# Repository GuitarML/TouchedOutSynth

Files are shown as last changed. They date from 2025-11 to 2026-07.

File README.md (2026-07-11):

# TouchedOut Sampler

The TouchedOut Polysynth is a polyphonic capacitive touch synth on a PCB, using the Daisy Seed. 
Two Adafruit MPR121 capacitive touch modules are used for keys and buttons. The firmware 
was designed and built using Arduino IDE with DaisyDuino. See Electrosmith's tutorials for
setting up the DaisyDuino environment with Arduino IDE. This repo also includes the
KiCad schematic and pcb files for ordering your own from a PCB manufacturer (JLCPcb gerbers provided).

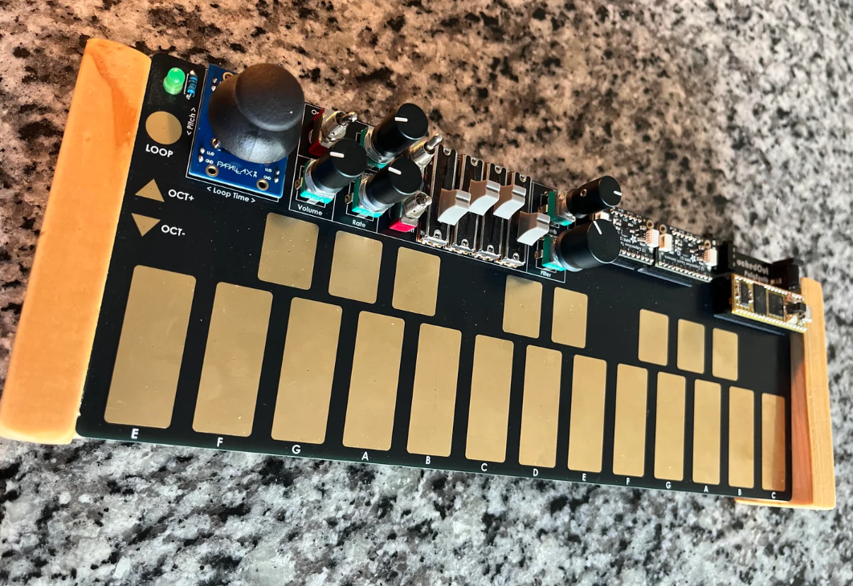
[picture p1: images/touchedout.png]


[Video Demos on YouTube](https://youtu.be/tRJoIYXkm-U?si=PkRd3XZ30BAMkGUb)

## Microphone Circuit
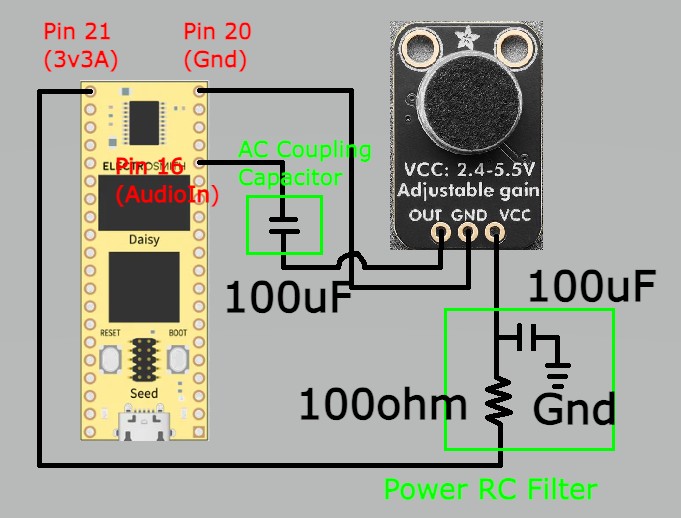
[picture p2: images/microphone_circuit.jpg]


The added microphone circuit for the TouchedOutSampler firmware is shown above. The mic used is from [Adafruit](https://www.adafruit.com/product/1063?srsltid=AfmBOooQ07_40sVdienoSQDztJte4-cMyLQY7wpDJVhW7ct12bVJHef1), MAX4466.
The 100uF capacitor on the audio line couples the audio to AC, as the output from the MAX4466 is DC coupled.
The RC filter using the 100 ohm resistior and 100uF capacitor was required for noise reduction. There 
is alot of noise coming from the Daisy Seed 3v3A power, but this RC filter does a good job of filtering it out. 

## Arduino IDE Setup

Follow this tutorial to set up DaisyDuino in Arduino IDE:
[How to Add Daisy Support to Arduino IDE](https://youtu.be/UyQWK8JFTps?si=kI6pP10nuPIkyu_V)

IMPORTANT!!! Updating Adafruit_MPR121 package to version 1.2.0 breaks functionality due to I2C incompatibilites. Use Adafruit_MPR121 version 1.1.3

Use these Tools settings in your Arduino IDE (pay attention to -O3 optimization and USB support: generic serial supercede USART)

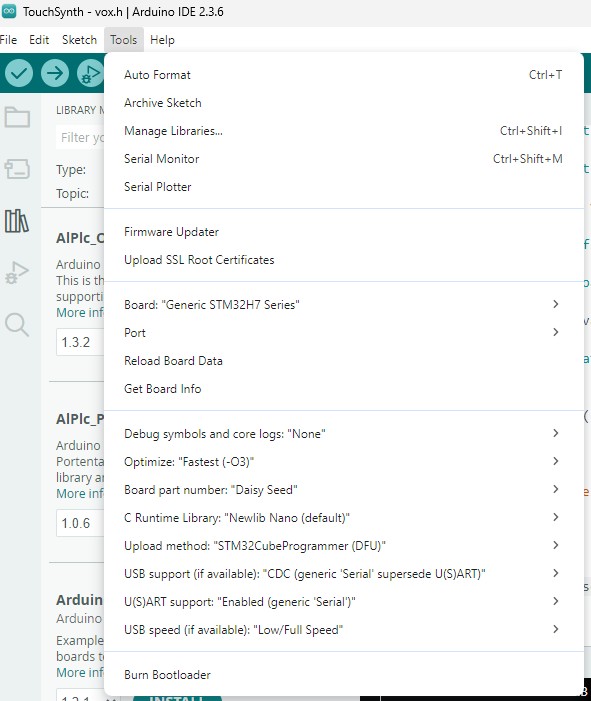
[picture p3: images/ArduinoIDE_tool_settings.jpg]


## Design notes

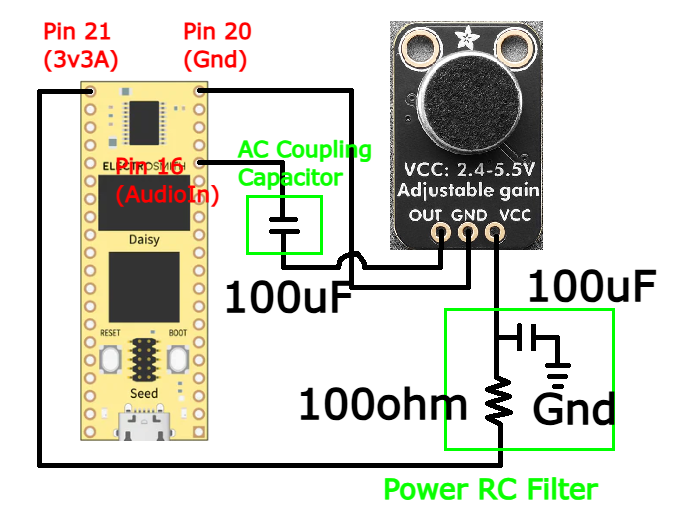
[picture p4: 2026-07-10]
images/microphone_circuit.png

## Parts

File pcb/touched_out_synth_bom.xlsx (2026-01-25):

Part | Qty | Description | Purchase Link
Daisy Seed | 1 |  | https://electro-smith.com/products/daisy-seed
MPR121 Module | 2 |  | https://www.adafruit.com/product/1982
2 Axis Joystick | 1 |  | https://www.adafruit.com/product/245
10K Linear Potentiometer | 5 |  | https://lovemyswitches.com/9mm-potentiometers-1-4-smooth-shaft-vertical-pcb-mount/ | Alternate small knob from Adafruit: https://www.adafruit.com/product/4133
On Off On Toggle | 1 |  | https://lovemyswitches.com/taiway-spdt-on-off-on-switch-pcb-long-shaft/
On On Toggle | 2 |  | https://lovemyswitches.com/taiway-sub-mini-spdt-on-on-switch-solder-lug-short-shaft/
10K 35mm Slide Potentiometer | 4 |  | https://www.adafruit.com/product/4271
1/8" Jack | 2 |  | https://www.taydaelectronics.com/pj-320a-3-5-mm-audio-socket-through-hole-pcb-silver-plated.html
1k Resistor | 1
LED | 1
10 ohm Resistor | 1
33 ohm Resistor | 1
TouchedOut PCB | 1

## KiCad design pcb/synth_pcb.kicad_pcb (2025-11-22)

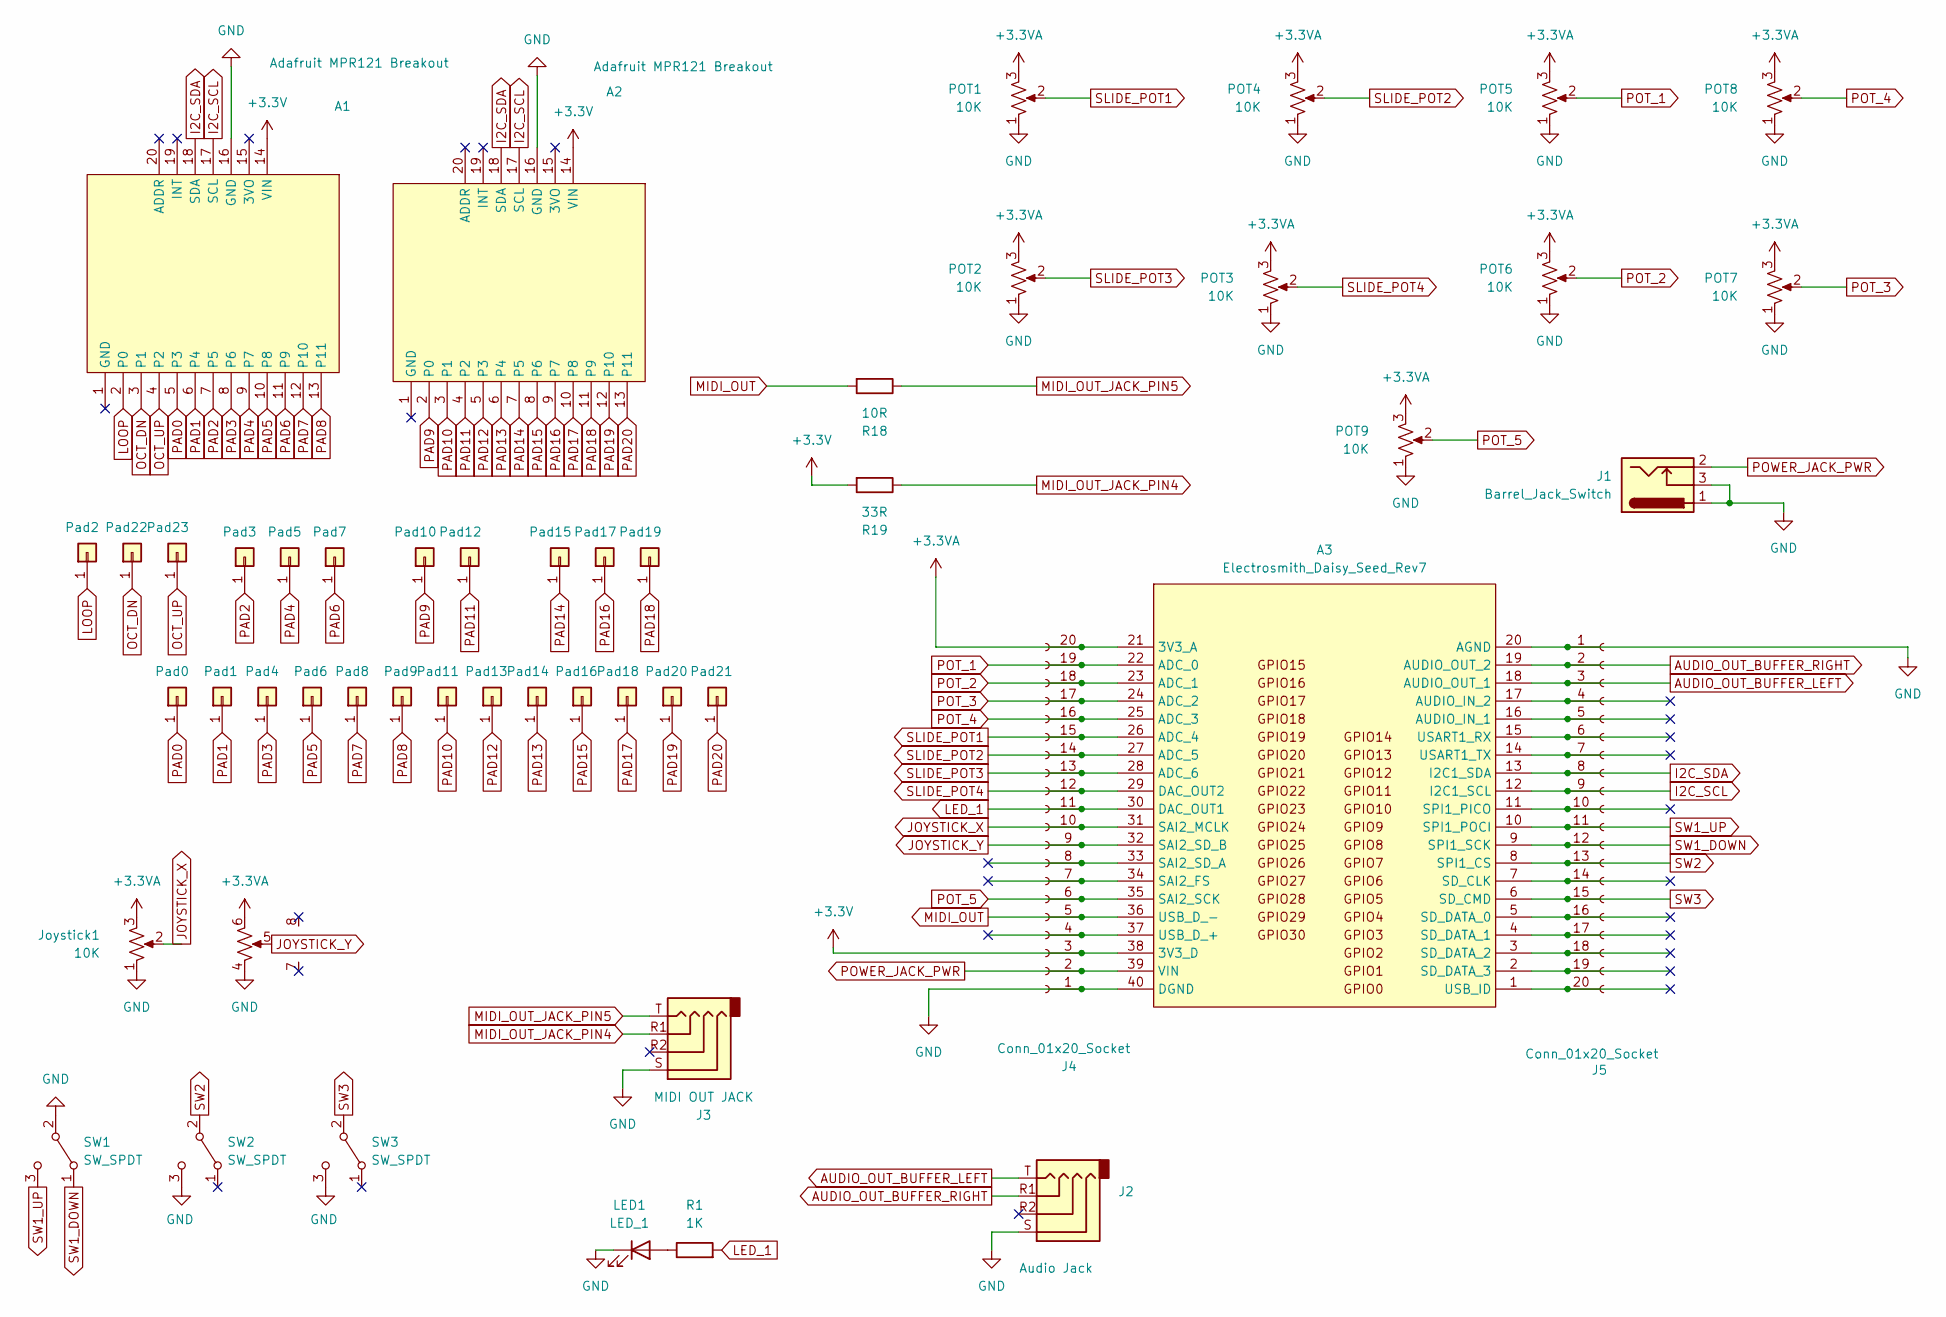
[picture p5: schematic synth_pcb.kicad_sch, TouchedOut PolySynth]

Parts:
A1, A2: Adafruit MPR121 Breakout; Adafruit_MPR121
A3: Electrosmith_Daisy_Seed_Rev7
J1: Barrel_Jack_Switch; Generic_PowerJack
J2: Audio Jack; Audio_TRRS-PJ-320A
J3: MIDI OUT JACK; Audio_TRRS-PJ-320A
J4, J5: Conn_01x20_Socket; PinSocket1x20_P2.54mm_Vertical_JLCPCB
Joystick1: 10K; Adafruit_2ax_joystick
LED1: LED_1; PinHeader_1x02_P2.54mm_Vertical
POT1, POT2, POT3, POT4: 10K; Slide_Potentiometer_35mm
POT5, POT6, POT7, POT8, POT9: 10K; Potentiometer_Bourns_PRS11R
Pad0, Pad1, Pad2, Pad3, Pad4, Pad5, Pad6, Pad7, Pad8, Pad9, Pad10, Pad11, Pad12, Pad13, Pad14, Pad15, Pad16, Pad17, Pad18, Pad19, Pad20, Pad21, Pad22, Pad23: TestPoint_THTPad_D2.0mm_Drill1.0mm
R1: 1K; R_Axial_DIN0207_L6.3mm_D2.5mm_P7.62mm_Horizontal
R18: 10R; R_Axial_DIN0207_L6.3mm_D2.5mm_P7.62mm_Horizontal
R19: 33R; R_Axial_DIN0207_L6.3mm_D2.5mm_P7.62mm_Horizontal
SW1, SW2, SW3: SW_SPDT; SW_Toggle_SPDT_lugs

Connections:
+3.3V: A1.14 (VIN), A2.14 (VIN), A3.38 (3V3_D), J4.3, R19.2
+3.3VA: A3.21 (3V3_A), J4.20, Joystick1.3, Joystick1.6, POT1.3, POT2.3, POT3.3, POT4.3, POT5.3, POT6.3, POT7.3, POT8.3, POT9.3
AUDIO_OUT_BUFFER_LEFT: A3.18 (AUDIO_OUT_1), J2.T, J5.3, J5.T
AUDIO_OUT_BUFFER_RIGHT: A3.19 (AUDIO_OUT_2), J2.R1, J5.2, J5.R1
GND: A1.16 (GND), A2.16 (GND), A3.20 (AGND), A3.40 (DGND), J1.1, J1.3, J2.S, J3.S, J4.1, J5.1, J5.S, Joystick1.1, Joystick1.4, LED1.1 (K), POT1.1, POT2.1, POT3.1, POT4.1, POT5.1, POT6.1, POT7.1, POT8.1, POT9.1, SW1.2 (B), SW2.3 (C), SW3.3 (C)
I2C_SCL: A1.17 (SCL), A2.17 (SCL), A3.12 (I2C1_SCL), J5.9
I2C_SDA: A1.18 (SDA), A2.18 (SDA), A3.13 (I2C1_SDA), J5.8
JOYSTICK_X: A3.31 (SAI2_MCLK), J4.10, Joystick1.2
JOYSTICK_Y: A3.32 (SAI2_SD_B), J4.9, Joystick1.5
LED_1: J4.11, R1.2
LOOP: A1.2 (P0), Pad2.1
MIDI_OUT: A3.36 (USB_D_-), J4.5, R18.2
MIDI_OUT_JACK_PIN4: J3.R1, R19.1
MIDI_OUT_JACK_PIN5: J3.T, R18.1
unnamed: A3.1 (USB_ID), J5.20
unnamed: A3.2 (SD_DATA_3), J5.19
unnamed: A3.3 (SD_DATA_2), J5.18
unnamed: A3.4 (SD_DATA_1), J5.17
unnamed: A3.5 (SD_DATA_0), J5.16
unnamed: A3.7 (SD_CLK), J5.14
unnamed: A3.11 (SPI1_PICO), J5.10
unnamed: A3.14 (USART1_TX), J5.7
unnamed: A3.15 (USART1_RX), J5.6
unnamed: A3.16 (AUDIO_IN_1), J5.5
unnamed: A3.17 (AUDIO_IN_2), J5.4
unnamed: A3.33 (SAI2_SD_A), J4.8
unnamed: A3.34 (SAI2_FS), J4.7
unnamed: A3.37 (USB_D_+), J4.4
unnamed: LED1.2 (A), R1.1
OCT_DN: A1.3 (P1), Pad22.1
OCT_UP: A1.4 (P2), Pad23.1
PAD0: A1.5 (P3), Pad0.1
PAD1: A1.6 (P4), Pad1.1
PAD2: A1.7 (P5), Pad3.1
PAD3: A1.8 (P6), Pad4.1
PAD4: A1.9 (P7), Pad5.1
PAD5: A1.10 (P8), Pad6.1
PAD6: A1.11 (P9), Pad7.1
PAD7: A1.12 (P10), Pad8.1
PAD8: A1.13 (P11), Pad9.1
PAD9: A2.2 (P0), Pad10.1
PAD10: A2.3 (P1), Pad11.1
PAD11: A2.4 (P2), Pad12.1
PAD12: A2.5 (P3), Pad13.1
PAD13: A2.6 (P4), Pad14.1
PAD14: A2.7 (P5), Pad15.1
PAD15: A2.8 (P6), Pad16.1
PAD16: A2.9 (P7), Pad17.1
PAD17: A2.10 (P8), Pad18.1
PAD18: A2.11 (P9), Pad19.1
PAD19: A2.12 (P10), Pad20.1
PAD20: A2.13 (P11), Pad21.1
POT_1: A3.22 (ADC_0), J4.19, POT5.2
POT_2: A3.23 (ADC_1), J4.18, POT6.2
POT_3: A3.24 (ADC_2), J4.17, POT7.2
POT_4: A3.25 (ADC_3), J4.16, POT8.2
POT_5: A3.35 (SAI2_SCK), J4.6, POT9.2
POWER_JACK_PWR: A3.39 (VIN), J1.2, J4.2
SLIDE_POT1: A3.26 (ADC_4), J4.15, POT1.2
SLIDE_POT2: A3.27 (ADC_5), J4.14, POT4.2
SLIDE_POT3: A3.28 (ADC_6), J4.13, POT2.2
SLIDE_POT4: A3.29 (DAC_OUT2), J4.12, POT3.2
SW1_DOWN: A3.9 (SPI1_SCK), J5.12, SW1.1 (A)
SW1_UP: A3.10 (SPI1_POCI), J5.11, SW1.3 (C)
SW2: A3.8 (SPI1_CS), J5.13, SW2.2 (B)
SW3: A3.6 (SD_CMD), J5.15, SW3.2 (B)

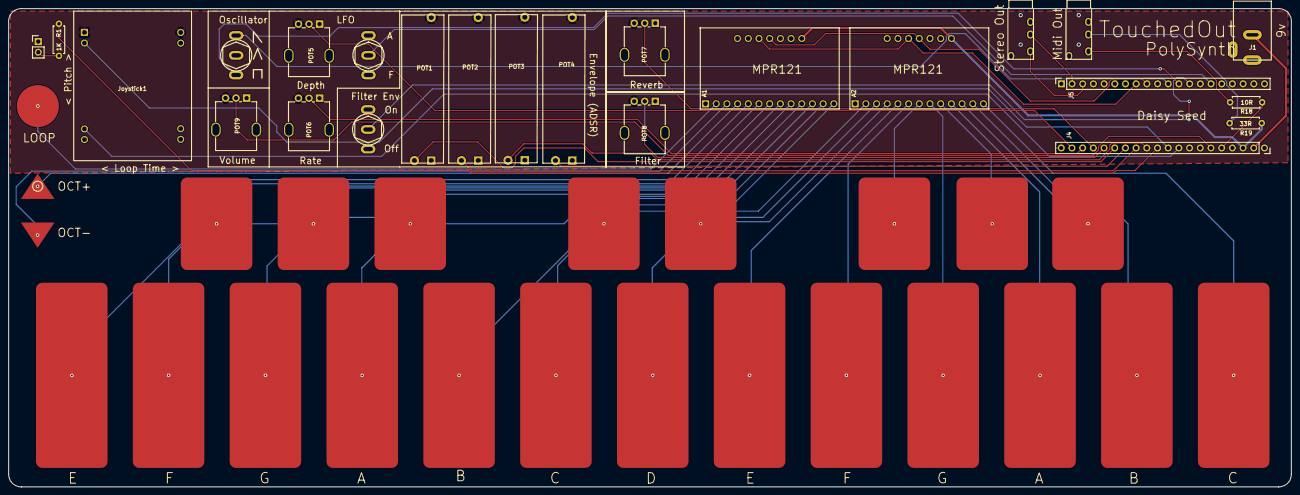
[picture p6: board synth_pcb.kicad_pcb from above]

Board: 2 copper layers, 304.7 x 113.6 mm, 48 parts (0 on the bottom side), 52 nets.

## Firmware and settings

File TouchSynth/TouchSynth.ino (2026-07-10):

#include "touch.h"
//#include "vox.h"
#include "varSpeedLooper.h"

#include "DaisyDuino.h"
#include "DaisyDSP.h"
//#include "daisysp.h"
using namespace daisysp;

////////////////////////////////////////////////////////////
/////////////////////// CONSTANTS //////////////////////////

static constexpr float kFrac = 1.f / 1023.f;
bool disableAfterTouch = true;

////////////////////////////////////////////////////////////
///////////////////// KNOBS & SWITCHES /////////////////////

#define JOYSTICK_X A9  // Looper Time
#define JOYSTICK_Y A10  // Filter Time (Overdrive?)

#define SLIDER_1 A4 // Attack
#define SLIDER_2 A6 // Decay
#define SLIDER_3 A7 // Sustain
#define SLIDER_4 A5 // Release

#define KNOB_1 A0 // LFO Rate
#define KNOB_2 A1 // LFO RATE
#define KNOB_3 A2 // Reverb Time / Amount
#define KNOB_4 A3 // Reverb Mix OR Overall Lowpass/Highpass Filter
#define KNOB_5 A11 // Reverb Mix OR Overall Lowpass/Highpass Filter

#define SWITCH_1_DOWN    D9  // VCO Shape
#define SWITCH_1_UP  D8  // VCO Shape

#define SWITCH_2_UP    D7  // fILTER ENV

#define SWITCH_3_UP   D5  // LFO Effect


#define LOOPER_LED  D23  // LED for Looper 


////////////////////////////////////////////////////////////
//////////////////////// MODULES ///////////////////////////

static simpletouch::Touch touch;
//static Vox vox;

////////////////////////////////////////////////////////////
//////////////////////// EFFECTS ///////////////////////////

int currentOctave = 0; // range of -3 to 3, 0 is middle c octave
bool first_start = true;
int c = 0;
float vVolume = 0.5;

// Reverb
ReverbSc        verb;
float ambient_mix = 0.0;

// Looper
unsigned long looperStartTime;
bool looper_cleared;
float speed_inputA;
float currentSpeedA;

// Looper Parameters
#define MAX_SIZE (48000 * 60 * 1) // 1 minute of floats at 48 khz
float DSY_SDRAM_BSS buf[MAX_SIZE];
varSpeedLooper  looper;
Oscillator      led_osc; // For pulsing the led when recording
float           ledBrightness;

// Filter
Svf filterLPHP;       // Low Pass and high pass
float vfilter;

// Sampler /////////////////// 
#define MAX_SAMPLE static_cast<int>(48000.0 * 10.0) // 10 second sample
#define MAX_SAMPLE_SIZET static_cast<size_t>(MAX_SAMPLE) 
float DSY_SDRAM_BSS audioSample[3][MAX_SAMPLE_SIZET];  // three sample banks selected with right toggle

bool recording = false;

int current_sample_size[3]{};
int sample_mode = 0;
int current_sample_bank = 0;

int recording_sample_index = 0;
bool trigger;

float middleC = 261.6256;

int trim1_index = 0;
int trim2_index = 0;

float ptrim1, ptrim2;

bool samplerModeOn = false;



///////////////////////////////////////////////////////// Delay

float global_delay_level = 0.0;
// Delay
#define MAX_DELAY static_cast<size_t>(24000) // 2 second max delay
//DelayLine<float, MAX_DELAY> delayLine;
DelayLine<float, MAX_DELAY> DSY_SDRAM_BSS delayLine;

struct delayStruct
{
    DelayLine<float, MAX_DELAY> *del;
    float                        currentDelay;
    float                        delayTarget;
    float                        feedback;
    float                        active = false;
    float                        volume = 1.0;
    
    float Process(float in)
    {
        //set delay times
        fonepole(currentDelay, delayTarget, .0002f);
        del->SetDelay(currentDelay);

        float read = del->Read();
        if (active) {
            del->Write((feedback * read) + in);
        } else {
            del->Write((feedback * read)); // if not active, don't write any new sound to buffer
        }

        return read * volume;
    }
};


delayStruct  delay1;


/////////////////////////////////////////////////////////////  SAMPLER VOICE

class SamplerVoice {
  public:
    SamplerVoice() {}
    ~SamplerVoice() {}
    void Init(float samplerate) {
        active_ = false;

        env_.Init(samplerate);
        env_.SetSustainLevel(1.0f);
        env_.SetAttackTime(0.05);
        env_.SetDecayTime(0.05);
        env_.SetReleaseTime(0.2); 

        playhead = static_cast<float>(trim1_index);  // set initial playhead to trim1 location
        play_speed_ = 1.0;
        is_first_sample = true;
        pitch_mod_ = 0.0;

    }

    // Process a single sample
    float getNextSample() {
        if (current_sample_size[current_sample_bank] == 0) return 0.0f;

        if (is_first_sample) {
            is_first_sample = false;
            playhead = static_cast<float>(trim1_index);
        }

        bool isReverse = false;
        if (trim1_index > trim2_index) {  // User could trigger reverse mid sample, so put here and not in initialization (TODO see if this works as expected)
            isReverse = true;
        }

        // If we get to the end of the sample, reset
        if (!isReverse && playhead >= static_cast<float>(trim2_index)) {
            playhead = static_cast<float>(trim1_index);
            if (sample_mode == 0 ) {
                active_ = false; // for now, end sample playback at end of sample in sample_mode= 0 (active remains true and repeats sample in other modes)
            } 
        }

        if (isReverse && playhead <= static_cast<float>(trim2_index)) {
            playhead = static_cast<float>(trim1_index);
            if (sample_mode == 0 ) {
                active_ = false; // for now, end sample playback at end of sample in sample_mode= 0 (active remains true and repeats sample in other modes)
            }
        }

        // Separate integer and fractional parts
        size_t index = static_cast<size_t>(playhead);
        float fraction = playhead - index;

        if (isReverse && index < 1) {
            return 0.0;
        }

        // Get current and next samples (handle boundary protection)
        float sample1 = audioSample[current_sample_bank][index];

        float sample2;
        if (!isReverse) {
            sample2 = (index + 1 < static_cast<float>(trim2_index)) ? audioSample[current_sample_bank][index + 1] : 0.0f;
        } else {
            sample2 = (index - 1 > static_cast<float>(trim2_index)) ? audioSample[current_sample_bank][index - 1] : 0.0f;
        }

        // Linear Interpolation
        float output = sample1 + static_cast<float>(fraction) * (sample2 - sample1);

        // Advance the playhead
        if (!isReverse) {
            playhead += play_speed_ * pitch_mod_; // TODO (To try) pitch_mod could be a convenient place to apply tape (or other) modulation
        } else {
            playhead -= play_speed_ * pitch_mod_;
        }

        // Short fade at end of sample to prevent clicks
        //   TODO: Maybe use this section for crossfading repeating samples (sample_mode = 1)
        float auto_fade = 1.0;
        if (!isReverse) {   // If forward 
            if (trim2_index - index < 240) { // 240 samples is 5 milliseconds at base pitch
                auto_fade = (trim2_index - index) / 240;
            }
        } else {            // If reverse
            if (index - trim1_index < 240) { // 240 samples is 5 milliseconds at base pitch
                auto_fade = (index - trim1_index) / 240;
            }
        }

        return output * auto_fade;
    }

    float Process() {
        if (active_) {
            float amp;
            amp = env_.Process(env_gate_);
            if (!env_.IsRunning()) {
                active_ = false;
                playhead = 0.0;
            } 

            return getNextSample() * amp;
            //return getNextSample() * (velocity_ / 127.f) * amp ;
            
        }
        return 0.f;
    }

    void OnNoteOn(float note, float velocity) {
        note_ = note;
        velocity_ = velocity;

        active_ = true;
        env_gate_ = true;
        play_speed_ = mtof(note_) / middleC;
        is_first_sample = true;

    }

    void OnNoteOff() { env_gate_ = false; }

    void SetAttack(float val) { env_.SetTime(ADSR_SEG_ATTACK, val); }

    void SetDecay(float val) { env_.SetTime(ADSR_SEG_DECAY, val); }

    void SetSustain(float val) { env_.SetSustainLevel(val); }

    void SetRelease(float val) { env_.SetTime(ADSR_SEG_RELEASE, val); }

    void SetPitchMod(float val) { pitch_mod_ = val; }

    inline bool IsActive() const { return active_; }
    inline float GetNote() const { return note_; }

  private:

    Adsr env_;
    float note_, velocity_;
    bool active_;
    bool env_gate_;
    float play_speed_;
    float playhead;
    bool is_first_sample;
    float pitch_mod_;
    
};

template <size_t max_voices> class SamplerVoiceManager {
  public:
    SamplerVoiceManager() {}
    ~SamplerVoiceManager() {}

    void Init(float samplerate) {
        for (size_t i = 0; i < max_voices; i++) {
            voices[i].Init(samplerate);
        }
    }

    float Process() {
        float sum;
        sum = 0.f;
        for (size_t i = 0; i < max_voices; i++) {
            sum += voices[i].Process();
        }
        return sum;
    }

    void OnNoteOn(float notenumber, float velocity) {
        SamplerVoice *v = FindFreeVoice();
        if (v == NULL)
            return;
        v->OnNoteOn(notenumber, velocity);
    }

    void OnNoteOff(float notenumber, float velocity) {
        for (size_t i = 0; i < max_voices; i++) {
            SamplerVoice *v = &voices[i];
            if (v->IsActive() && v->GetNote() == notenumber) {
                v->OnNoteOff();
            }
        }
    }

    void SetAttack(float all_val)
    {
        for(size_t i = 0; i < max_voices; i++) {
            voices[i].SetAttack(all_val);
        }
    }

    void SetDecay(float all_val)
    {
        for(size_t i = 0; i < max_voices; i++) {
            voices[i].SetDecay(all_val);
        }
    }

    void SetSustain(float all_val)
    {
        for(size_t i = 0; i < max_voices; i++) {
            voices[i].SetSustain(all_val);
        }
    }

    void SetRelease(float all_val)
    {
        for(size_t i = 0; i < max_voices; i++) {
            voices[i].SetRelease(all_val);
        }
    }

    void SetPitchMod(float all_val) {
        for(size_t i = 0; i < max_voices; i++) {
            voices[i].SetPitchMod(all_val);
        }
    }


    void FreeAllVoices() {
        for (size_t i = 0; i < max_voices; i++) {
            voices[i].OnNoteOff();
        }
    }



  private:
    SamplerVoice voices[max_voices];
    SamplerVoice *FindFreeVoice() {
        SamplerVoice *v = NULL;
        for (size_t i = 0; i < max_voices; i++) {
            if (!voices[i].IsActive()) {
                v = &voices[i];
                break;
            }
        }
        return v;
    }
};


// Sampler
//static SamplerVoiceManager<12> sampler_voice_handler;
SamplerVoiceManager<12> sampler_voice_handler;


////////////////////////////////////////////////////////////
///////////////////// CALLBACKS ////////////////////////////

bool knobMoved(float old_value, float new_value)
{
    float tolerance = 0.003;
    if (new_value > (old_value + tolerance) || new_value < (old_value - tolerance)) {
        return true;
    } else {
        return false;
    }
}

void looperPadTouched() {

   if (samplerModeOn) {
        recording = true;
        ledBrightness = 1.0;

   } else {
       looperStartTime = millis();

       // Looper footswitch pressed (start/stop recording)
       looper.TrigRecord();
       if (!looper.Recording()) {  // Turn on LED if not recording and in playback
         ledBrightness = 1.0;
       }

       looper_cleared = false;
   }

}

// Pad Released stop sample recording if in sampler mode
void looperPadReleased() {
   if (samplerModeOn) {
       recording = false;
       recording_sample_index = 0;
       ledBrightness = 0.0;
   }
}

void OnPadTouch(uint16_t pad) {

  // Handle non-note touch (looper, up/down octave)
  if (pad == 0) {
    looperPadTouched();

  } else if (pad == 1) { // If octave down
    currentOctave -= 1;
    if (currentOctave < -3) {
      currentOctave = -3;
    }
    //vox.ReleaseAllNotes(); // Work around to prevent notes from hanging, would be better to transfer note pitch though

  } else if (pad == 2) { // If octave up
    currentOctave += 1;
    if (currentOctave > 3) {
      currentOctave = 3;
    }
    //vox.ReleaseAllNotes(); // Work around to prevent notes from hanging, would be better to transfer note pitch though
    // TODO Need to add a function like this to sampler?

  // Notes
  } else {
  
    auto note_num = pad; // pad for notes is 3 to 23 (3 is E3, Middle C is 11, C5 is 23)

    // convert pad to a midi note, then convert midi note to frequency
    float midi_note = pad + 49; // start at E3 (accounting for the fact pad key number starts at 3)

    // Apply current octave
    midi_note = midi_note + currentOctave * 12;
    
    sampler_voice_handler.OnNoteOn(midi_note, 127.0);

  }

}
void OnPadRelease(uint16_t pad) {

  // Handle non-note touch (looper, up/down octave)
  if (pad == 0) {
    looperPadReleased();

  } else if (pad == 1 || pad == 2) { // If octave up or down 

  // Notes
  } else {

    auto note_num = pad; // pad for notes is 3 to 23 (3 is E3, Middle C is 11, C5 is 23)

    // convert pad to a midi note, then convert midi note to frequency
    float midi_note = pad + 49; // start at E3 (accounting for the fact pad key number starts at 3)

    // Apply current octave
    midi_note = midi_note + currentOctave * 12;

    sampler_voice_handler.OnNoteOff(midi_note, 0.0);

  }

}

void OnPadAftertouch(uint16_t pad, float aftertouch) {

    auto note_num = pad; // pad is 0 to 23

    if (!samplerModeOn) {
        if (pad == 0) {  // If the looper pad is being held
            unsigned long interval = millis() - looperStartTime; // Determine length of touch on looper pad

            // If held long than 1 second, clear loop ( but only once )
            if (interval > 1000 && !looper_cleared) {
                looper.Clear();
                looper_cleared = true;
                ledBrightness = 0.0;
            }
        }
    }

    // Keys Aftertouch
    /*
    if (pad > 2 && disableAfterTouch == false) {

        // convert pad to a midi note, then convert midi note to frequency
        float midi_note = pad + 49; // start at E3 (accounting for the fact pad key number starts at 3)

        // Apply current octave
        midi_note = midi_note + currentOctave * 12;

        vox.Aftertouch(midi_note, aftertouch); // Setting amp to 0 to turn note off (0.0 freq is just placeholder, not used)
    }
    */
}


///////////////////////////////////////////////////////////////
///////////////////// AUDIO CALLBACK //////////////////////////

float bus[2];
void AudioCallback(float **in, float **out, size_t size) {


  float sendl, sendr, wetl, wetr;  // Reverb Inputs/Outputs 

  /*
  if (c < 50) {
    c+=1;
  } else {
    first_start = false;
  }
  */

  for (size_t i = 0; i < size; i++) {


    float input = in[0][i];

    // Record input audio while footswitch is held, or until max buffer is reached
    if (!samplerModeOn) {
       recording = false;
       recording_sample_index = 0;
    }
    if (recording && samplerModeOn) {
        audioSample[current_sample_bank][recording_sample_index] = input;
        current_sample_size[current_sample_bank] = recording_sample_index;
        recording_sample_index++;
                
        if (recording_sample_index >= MAX_SAMPLE) {
            recording = false;
            recording_sample_index = 0;
            current_sample_size[current_sample_bank] = MAX_SAMPLE;

        }

    }

    // Handle Looper LED
    if (looper.Recording()) {  // Only update the led oscillations if currently recording
        ledBrightness = led_osc.Process() * 0.8 + 0.6;
    }

    float sampler_output = sampler_voice_handler.Process() * vVolume * 5.0; //5 is just volume scaling

    // Lowpass Highpass filter //
    float filtered_sum = 0.0;
    filterLPHP.Process(sampler_output);


    if (vfilter <= 0.5) {  // is lowpass
        bus[0] = bus[1] = filterLPHP.Low();
    } else {  // is highpass
        bus[0] = bus[1] = filterLPHP.High();
    }

    // Process Delay (Note: delay and reverb currently processed before looper, to bake effects into loop
    float delay_input = bus[0];
    float delay_out = delay1.Process(delay_input);  

    sendl = sendr = bus[0];

    verb.Process(sendl, sendr, &wetl, &wetr); // Note:Reverb added after looper



   
    // Smooth out Looper transitions
    fonepole(currentSpeedA, speed_inputA, .00006f); 

    if (currentSpeedA < 0.0) {
      looper.SetReverse(true);
    } else {
      looper.SetReverse(false);
    }
    float speed_inputAabs = abs(currentSpeedA);
    looper.SetIncrementSize(speed_inputAabs);

    float loop_out = looper.Process(bus[0] + delay_out + wetl); // TODO: Mono looper for now, is there a need for stereo?



    out[0][i] = (bus[0] * (1.0 - ambient_mix)  + loop_out + ((wetl / 30.0) + delay_out) * ambient_mix);
    out[1][i] = (bus[0] * (1.0 - ambient_mix)  + loop_out + ((wetr / 30.0) + delay_out) * ambient_mix);


  }
}

///////////////////////////////////////////////////////////////
////////////////////////// SETUP //////////////////////////////
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
void loop() {

  touch.Process();

  // Process Controls

  // REVERB CONTROLS
  
  float vReverbTime = static_cast<float>(analogRead(KNOB_3)) * kFrac;
  verb.SetFeedback(vReverbTime);

  ambient_mix = vReverbTime;
  if (vReverbTime < 0.05) {
      delay1.volume = 0.0;
      delay1.feedback = 0.0;
  } else if (vReverbTime < 0.55) {
      delay1.volume = (vReverbTime - 0.05) * 1.6;
      delay1.feedback = (vReverbTime - 0.05) * 1.2;
  } else {
      delay1.volume = 0.8;
      delay1.feedback = 0.6;
  }



  // Joystick
  float vPitchMod = static_cast<float>(analogRead(JOYSTICK_Y)) * kFrac; 

  //vPitchMod = vPitchMod * 2.0; // map value from 0.5 to +1
  if (vPitchMod <= 0.45) {
      sampler_voice_handler.SetPitchMod(vPitchMod * 1.1111 + 0.5); // map 0.5 to 1
  } else if (vPitchMod >= 0.55) {
      sampler_voice_handler.SetPitchMod((vPitchMod - 0.55) * 2.2222   + 1.0); // map 1 to 2
  } else {  // If knob is centered (within 10% range) lock at no pitch mod
      sampler_voice_handler.SetPitchMod(1.0);
  }


  // Looper CONTROLS
  float vLoopSpeed = static_cast<float>(analogRead(JOYSTICK_X)) * kFrac;
  if (vLoopSpeed <= 0.45 && !looper.Recording()) {
    speed_inputA = vLoopSpeed * 6.6667 - 2.0; // maps 0 to 0.45 control to -2x to 1x speed

  } else if (vLoopSpeed >= 0.55 && !looper.Recording()) {
    speed_inputA = 1.0 + 2.222 * (vLoopSpeed - 0.55) ;  // maps 0.55 to 1.0 control to 1x to 2x speed

  } else {  // If knob is centered (within 10% range) lock at 1x speed or looper is recording
    speed_inputA = 1.0;
  }


  // Voice Controls ///////////////////////////////////////////////

  // VCO Shape
  auto switch1_up = static_cast<uint32_t>(digitalRead(SWITCH_1_UP));
  auto switch1_down = static_cast<uint32_t>(digitalRead(SWITCH_1_DOWN));
  if (switch1_up == LOW) {

    current_sample_bank = 0;
  
  } else if (switch1_down == LOW) {
    current_sample_bank = 2;

  } else {
    current_sample_bank = 1;

  }

  // Sampler Mode On/Off
  auto switch2_up = static_cast<uint32_t>(digitalRead(SWITCH_2_UP));

  if (switch2_up == LOW) {
    samplerModeOn = true;

  } else {
    samplerModeOn = false;
  }

  // ADSR ///
  float vAttack = static_cast<float>(analogRead(SLIDER_1)) * kFrac;
  //float temp_attack = 0.4;
  sampler_voice_handler.SetAttack(vAttack); 

  float vDecay = static_cast<float>(analogRead(SLIDER_2)) * kFrac;
  //float temp_decay = 0.04;
  sampler_voice_handler.SetDecay(vDecay); 


  float vSustain = static_cast<float>(analogRead(SLIDER_3)) * kFrac;
  sampler_voice_handler.SetSustain(vSustain + 0.001); 


  float vRelease = static_cast<float>(analogRead(SLIDER_4)) * kFrac;
  //float temp_release = 0.4;
  sampler_voice_handler.SetRelease(vRelease); 


  // Sample trim controls
  float vtrim2 = static_cast<float>(analogRead(KNOB_2)) * kFrac;
  float vtrim1 = static_cast<float>(analogRead(KNOB_1)) * kFrac;

  float current_sample_size_float = static_cast<float>(current_sample_size[current_sample_bank]);


  if (knobMoved(ptrim1, vtrim1) || first_start) {
      ptrim1 = vtrim1;

  }
  trim1_index = static_cast<int>(ptrim1 * current_sample_size_float);

  if (knobMoved(ptrim2, vtrim2) || first_start) {
      ptrim2 = vtrim2;
  }
  trim2_index = static_cast<int>(ptrim2 * current_sample_size_float);
  first_start = false;

  auto switch3_up = static_cast<uint32_t>(digitalRead(SWITCH_3_UP));
  if (switch3_up == LOW) {
    sample_mode = 1;
  } else {
    sample_mode = 0;
  }

  vfilter = static_cast<float>(analogRead(KNOB_4)) * kFrac;

  float cutoff_filter;
  if (vfilter <= 0.5) {

      cutoff_filter = vfilter * vfilter * 2 * 18000.0 + 150.0; // exponential range 150 to 18150 as knob goes from 0 to 0.5
      filterLPHP.SetFreq(cutoff_filter);

  } else {
      cutoff_filter = ((vfilter - 0.5) * 2.0) * ((vfilter - 0.5) * 2.0) * 3000.0;
      filterLPHP.SetFreq(cutoff_filter); // exp range 0 to 3000 as knob goes from 0.5 to 1.0

  }
  
  vVolume = static_cast<float>(analogRead(KNOB_5)) * kFrac;

  // Looper LED Brightness
  int ledBrightness_int = static_cast<int>(ledBrightness * 125.0 + 130.0);
  analogWrite(LOOPER_LED, ledBrightness_int); // ledBrightness_int needs to be 0 to 255

  //delay(4); // removed delay
}

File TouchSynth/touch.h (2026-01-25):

#pragma once

#include "DaisyDuino.h"
#include "Adafruit_MPR121.h"  // IMPORTANT!!! Updating to version 1.2.0 broke it, I2C incompatibilites? Built, uploaded, but touches were unresponsive. Rolled back to 1.1.3 to fix.
#include <array>


namespace simpletouch {

///////////////////////////////////////////////////////////////
//////////////////////// TOUCH SENSOR /////////////////////////

class Touch {
  public:
    Touch():
      _state { 0 },
      _on_touch { nullptr },
      _on_release { nullptr }
      {}

    void Init() {
      
      if (!_cap.begin(0x5A)) {
        Serial.println("MPR121 0x5A not found, check wiring?");
        while (1) {
          Serial.println("PLEASE CONNECT 0x5A MPR121 TO CONTINUE TESTING");
          delay(200);
        }
      }
      // Make sure to double check address used here
      if (!_cap2.begin(0x5B)) { // This address is when back pad is soldered (ADDR connected to 3v3) 
        Serial.println("MPR121 0x5B not found, check wiring?");
        while (1) {
          Serial.println("PLEASE CONNECT 0x5B MPR121 TO CONTINUE TESTING");
          delay(200);
        }
      }
    }

    // Register note on callback
    void SetOnTouch(void(*on_touch)(uint16_t pad)) {
      _on_touch = on_touch;
    }

    void SetOnRelease(void(*on_release)(uint16_t pad)) {
      _on_release = on_release;
    }

    void SetOnAftertouch(void(*on_aftertouch)(uint16_t pad, float volume_aftertouch)) {
      _on_aftertouch = on_aftertouch;
    }

    bool IsTouched(uint16_t pad) {
      return _state & (1 << pad);
    }

    bool HasTouch() {
      return _state > 0;
    }

    void Process() {
        uint16_t pad;
        bool is_touched;
        bool was_touched;

        // Process first MPR121 

        auto state = _cap.touched();
        for (uint16_t i = 0; i < 12; i++) { // modified to leave out first touchpad

          pad = 1 << i;
          is_touched = state & pad;
          was_touched = _state & pad;
          if (_on_touch != nullptr && is_touched && !was_touched) {
            _on_touch(i);
            Serial.print("Pad Touch Detected: ");
            Serial.println(i);

          }
          else if (_on_release != nullptr && was_touched && !is_touched) {
            _on_release(i);
            Serial.print("Pad Release Detected: ");
            Serial.println(i);
            
          }

          // Get the filtered data for the channel
          uint16_t filtered = _cap.filteredData(i);

          // Get the baseline data for the channel
          uint16_t baseline = _cap.baselineData(i);

          // The 'pressure' is the difference between baseline and filtered data
          // This value will increase as a touch becomes more substantial
          int16_t pressure = baseline - filtered;

          // You can set a threshold to ignore minor fluctuations
          if (pressure > 0) { // Adjust threshold as needed // Reduced threshold from 10 to 5 to try to prevent no sound on touch TODO verify if this helps
            Serial.print("Electrode ");
            Serial.print(i);
            Serial.print(": Pressure = ");
            Serial.println(pressure);

            float aftertouch = pressure / 150.0;  // TODO test sensitivity, capacitence measurements
            _on_aftertouch(i, aftertouch);

          }

        }
        _state = state;



        // Process second MPR121 

        auto state2 = _cap2.touched();
        for (uint16_t i = 0; i < 12; i++) { // modified to leave out first touchpad

          pad = 1 << i;
          is_touched = state2 & pad;
          was_touched = _state2 & pad;
          if (_on_touch != nullptr && is_touched && !was_touched) {
            _on_touch(i + 12);  // Adding 12 because we need to count first MPR121 pads
            Serial.print("Pad Touch Detected (2nd MPR121): ");
            Serial.println(i);

          }
          else if (_on_release != nullptr && was_touched && !is_touched) {
            _on_release(i + 12);  // Adding 12 because we need to count first MPR121 pads
            Serial.print("Pad Release Detected (2nd MPR121): ");
            Serial.println(i);
            
          }

          // Get the filtered data for the channel
          uint16_t filtered = _cap2.filteredData(i);

          // Get the baseline data for the channel
          uint16_t baseline = _cap2.baselineData(i);

          // The 'pressure' is the difference between baseline and filtered data
          // This value will increase as a touch becomes more substantial
          int16_t pressure = baseline - filtered;

          
          // You can set a threshold to ignore minor fluctuations
          if (pressure > 0) { // Adjust threshold as needed // Reduced threshold from 10 to 5 to try to prevent no sound on touch TODO verify if this helps
            Serial.print("Electrode (2nd MPR121) ");
            Serial.print(i);
            Serial.print(": Pressure = ");
            Serial.println(pressure);

            float aftertouch = pressure / 150.0;
            _on_aftertouch(i + 12, aftertouch);  // Adding 12 because we need to count first MPR121 pads

          }

        }
        _state2 = state2;

    }

  private:

    void(*_on_touch)(uint16_t pad);
    void(*_on_release)(uint16_t pad);
    void(*_on_aftertouch)(uint16_t pad, float volume_aftertouch);

    Adafruit_MPR121 _cap;
    Adafruit_MPR121 _cap2;
    uint16_t _state;
    uint16_t _state2;
};




};

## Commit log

2026-01-25 Updates for initial release
    [touched_out_synth_bom.xlsx]
2026-07-10 Initial sampler firmware
2026-07-10 Updated readme and circuit reference image
